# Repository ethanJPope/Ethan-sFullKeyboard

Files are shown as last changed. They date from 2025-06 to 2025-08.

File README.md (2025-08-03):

# Full Keyboard

My keybaord is a 100% version with a hotswappable pcb with custom USB_C Daughter Board PCB. 

## Why I made this Project
- I want a finished project
- Learn how to make a complex pcb
- Make a full and finished CAD Project

## PCB

**Keyboard PCB**

 

**USB_C DAUGHTER BOARD**

 

## CAD


## Final Product
0047bdcb-f9c8-4a06-a499-ea2659d34d8d~1

## BOM

| Item | Description | Unit Price | Supplier |
|---|---|---|---|
| 1 | Custom Keyboard PCB | $55.82 | JLCPCB |
| 2 | PCB Components | $22.54 | LCSC |
| 3 | USB-C Cable | $6.23 | AliExpress |
| 4 | Hot Swap Sockets | $6.90 | AliExpress |
| 5 | Stabilizers | $5.97 | AliExpress |
| 6 | Switches | $21.65 | AliExpress |
| 7 | Poron Foam | $5.70 | AliExpress |
| 8 | Keycaps Set | $19.99 | Amazon |

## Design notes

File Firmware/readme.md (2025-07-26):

# full_keyboard

full_keyboard

*A short description of the keyboard/project*

* Keyboard Maintainer: [EthanP](https://github.com/ethanJPope)
* Hardware Supported: *The PCBs, controllers supported*
* Hardware Availability: *Links to where you can find this hardware*

Make example for this keyboard (after setting up your build environment):

    make full_keyboard:default

Flashing example for this keyboard:

    make full_keyboard:default:flash

See the [build environment setup](https://docs.qmk.fm/#/getting_started_build_tools) and the [make instructions](https://docs.qmk.fm/#/getting_started_make_guide) for more information. Brand new to QMK? Start with our [Complete Newbs Guide](https://docs.qmk.fm/#/newbs).

## Bootloader

Enter the bootloader in 3 ways:

* **Bootmagic reset**: Hold down the key at (0,0) in the matrix (usually the top left key or Escape) and plug in the keyboard
* **Physical reset button**: Briefly press the button on the back of the PCB - some may have pads you must short instead
* **Keycode in layout**: Press the key mapped to `QK_BOOT` if it is available

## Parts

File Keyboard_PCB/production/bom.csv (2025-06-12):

Designator | Footprint | Quantity | Value | LCSC Part #
"-"1, "0"1, "1, "1"1, "2"1, "3"1, "4"1, "5"1, "6"1, "7"1, "8"1, "9"1, "="1, "?"1, ;1, <1, >1, A1, B1, C1, D105, Delete1, DownArrow1, E1, ESC1, End1, F10, F11, F12, F13, F2, F3, F4, F5, F6, F7, F8, F9, Func1, G1, H1, Home1, I1, Insert1, J2, K1, L1, LeftArrow1, M1, N1, Num*1, Num-1, Num.1, Num/1, Num1, Num2, Num3, Num4, Num5, Num6, Num7, Num8, Num9, NumLock1, O1, P1, PauseBreak1, PgDn1, PgUp1, PrtSc1, Q1, R4, RightArrow1, S1, ScrollLock1, T1, Tilde1, U2, UpArrow1, V1, W1, X1, Y1, Z1, {1, }1 | Hotswap_MX_1.00u | 86 | Keyswitch
Backspace1, Num0 | Hotswap_MX_2.00u | 2 | Keyswitch
C10, C11, C13, C16, C7 | Capacitor_0402 | 5 | 100nF | C307331
C12, C17 | Capacitor_0402 | 2 | 4.7uF | C23733
C14 | Capacitor_0402 | 1 | 10nF | C15195
C15 | Capacitor_0402 | 1 | 1uF | C52923
CapsLock1 | Hotswap_MX_1.75u | 1 | Keyswitch
D1, D10, D100, D101, D102, D103, D104, D11, D12, D13, D14, D15, D16, D17, D18, D19, D2, D20, D21, D22, D23, D24, D25, D26, D27, D28, D29, D3, D30, D31, D32, D33, D34, D35, D36, D37, D38, D39, D4, D40, D41, D42, D43, D44, D45, D46, D47, D48, D49, D5, D50, D51, D52, D53, D54, D55, D56, D57, D58, D59, D6, D60, D61, D62, D63, D64, D65, D66, D67, D68, D69, D7, D70, D71, D72, D73, D74, D75, D76, D77, D78, D79, D8, D80, D81, D82, D83, D84, D85, D86, D87, D88, D89, D9, D90, D91, D92, D93, D94, D95, D96, D97, D98, D99 | Diode_SOD-123 | 104 | Diode
Enter1, Shift1 | Hotswap_MX_2.25u | 2 | Keyswitch
J3 | JST_EH_B4B-EH-A_1x04_P2.50mm_Vertical | 1 | Conn_01x04_Pin
LeftAlt1, LeftControl1, LeftWin1, Menu1, RightAlt1, RightControl1, RightWin1 | Hotswap_MX_1.25u | 7 | Keyswitch
Num+1, NumEnter1 | Hotswap_MX_2.00u_90deg | 2 | Keyswitch
R1 | Resistor_0402 | 1 | 10k | C25744
RightShift1 | Hotswap_MX_2.75u | 1 | Keyswitch
SW1 | Button_TL3342 | 1 | SW_Push | C115351
Space1 | Hotswap_MX_6.25u | 1 | Keyswitch
Tab1, \1 | Hotswap_MX_1.50u | 2 | Keyswitch
U1 | Package_LQFP-48_7x7mm_P0.5 | 1 | STM32F072CBT6 | C81720

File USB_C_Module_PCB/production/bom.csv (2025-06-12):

Designator | Footprint | Quantity | Value | LCSC Part #
C8, C9 | Capacitor_0402 | 2 | 1uF | C52923
F1 | Fuse_0603 | 1 | 500mA | C210357
J1 | USB_C_HRO_TYPE-C-31-M-12 | 1 | USB_C | C165948
J2 | JST_EH_B4B-EH-A_1x04_P2.50mm_Vertical | 1 | Conn_01x04_Pin
R2, R3 | Resistor_0402 | 2 | 5.1k | C25905
U3 | Voltage_SOT-23 | 1 | XC6206 | C5446
U4 | ESD_SOT-23-6 | 1 | USBLC6-2SC6 | C2827654

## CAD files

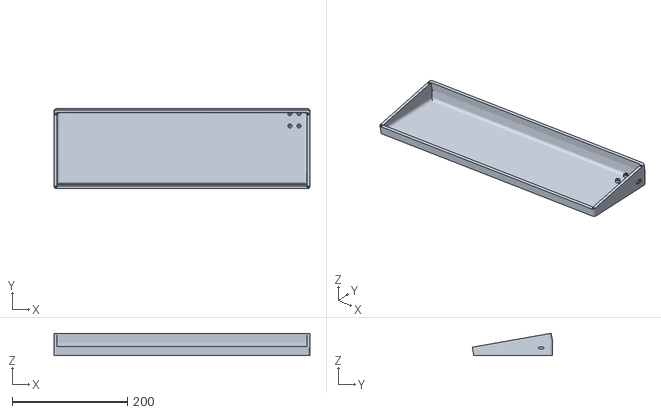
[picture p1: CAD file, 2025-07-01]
Production/BottomCase.stl
443.8 x 139.4 x 38.9

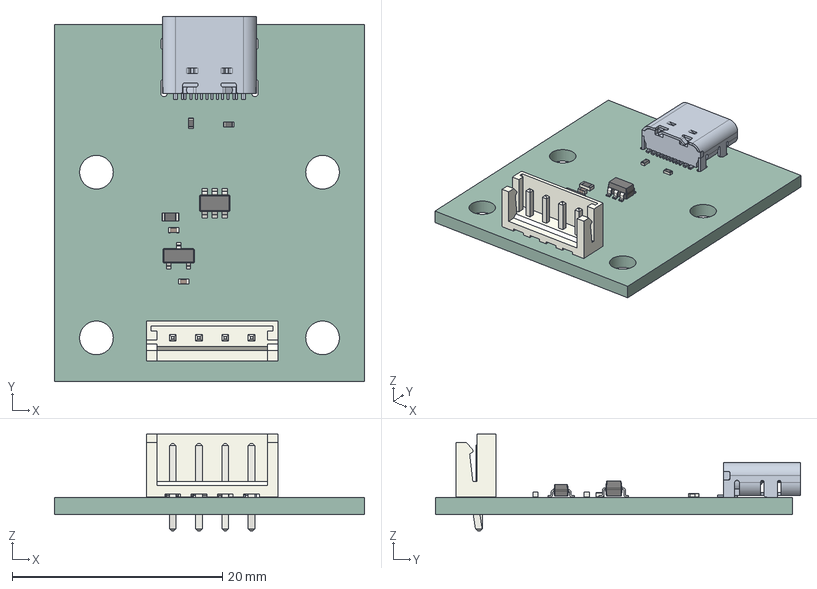
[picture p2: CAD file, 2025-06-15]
USB_C_Module_PCB/usb_c_module.step
29.5 x 34.7 x 9.20 mm
R_0402_1005Metric x 2
TYPE-C-31-M-12
SOT_23_6
C_0402_1005Metric x 2
JST_B4B_EH_A
SOT_23
Fuse_0603_1608Metric
usb_c_module_PCB

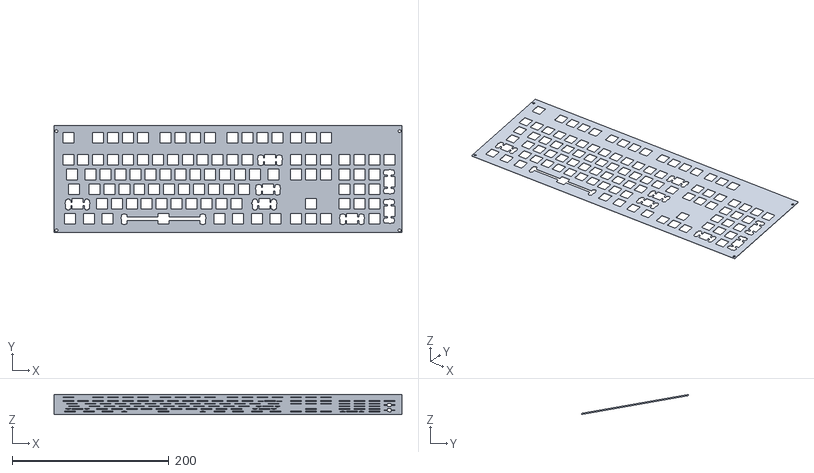
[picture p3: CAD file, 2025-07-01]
Production/Plate.stl
443.8 x 137.1 x 25.6

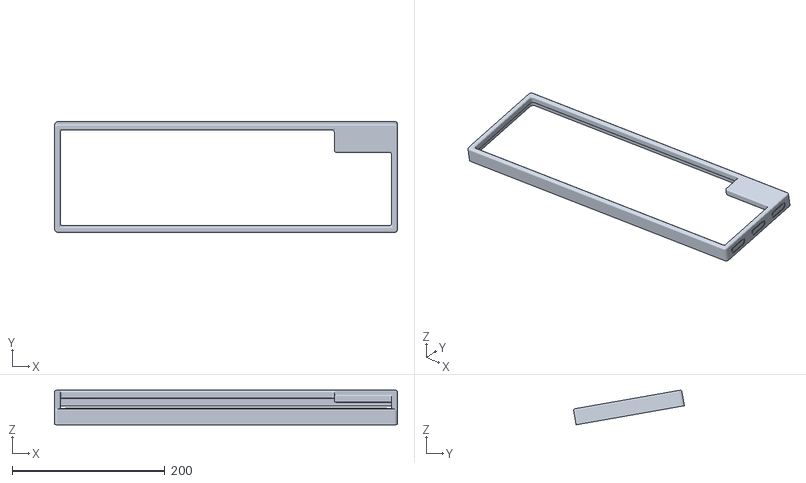
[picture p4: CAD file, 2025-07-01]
Production/TopCase.stl
448.8 x 145.1 x 45.4

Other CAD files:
USB_C_Module_PCB/Case_BTM.stl

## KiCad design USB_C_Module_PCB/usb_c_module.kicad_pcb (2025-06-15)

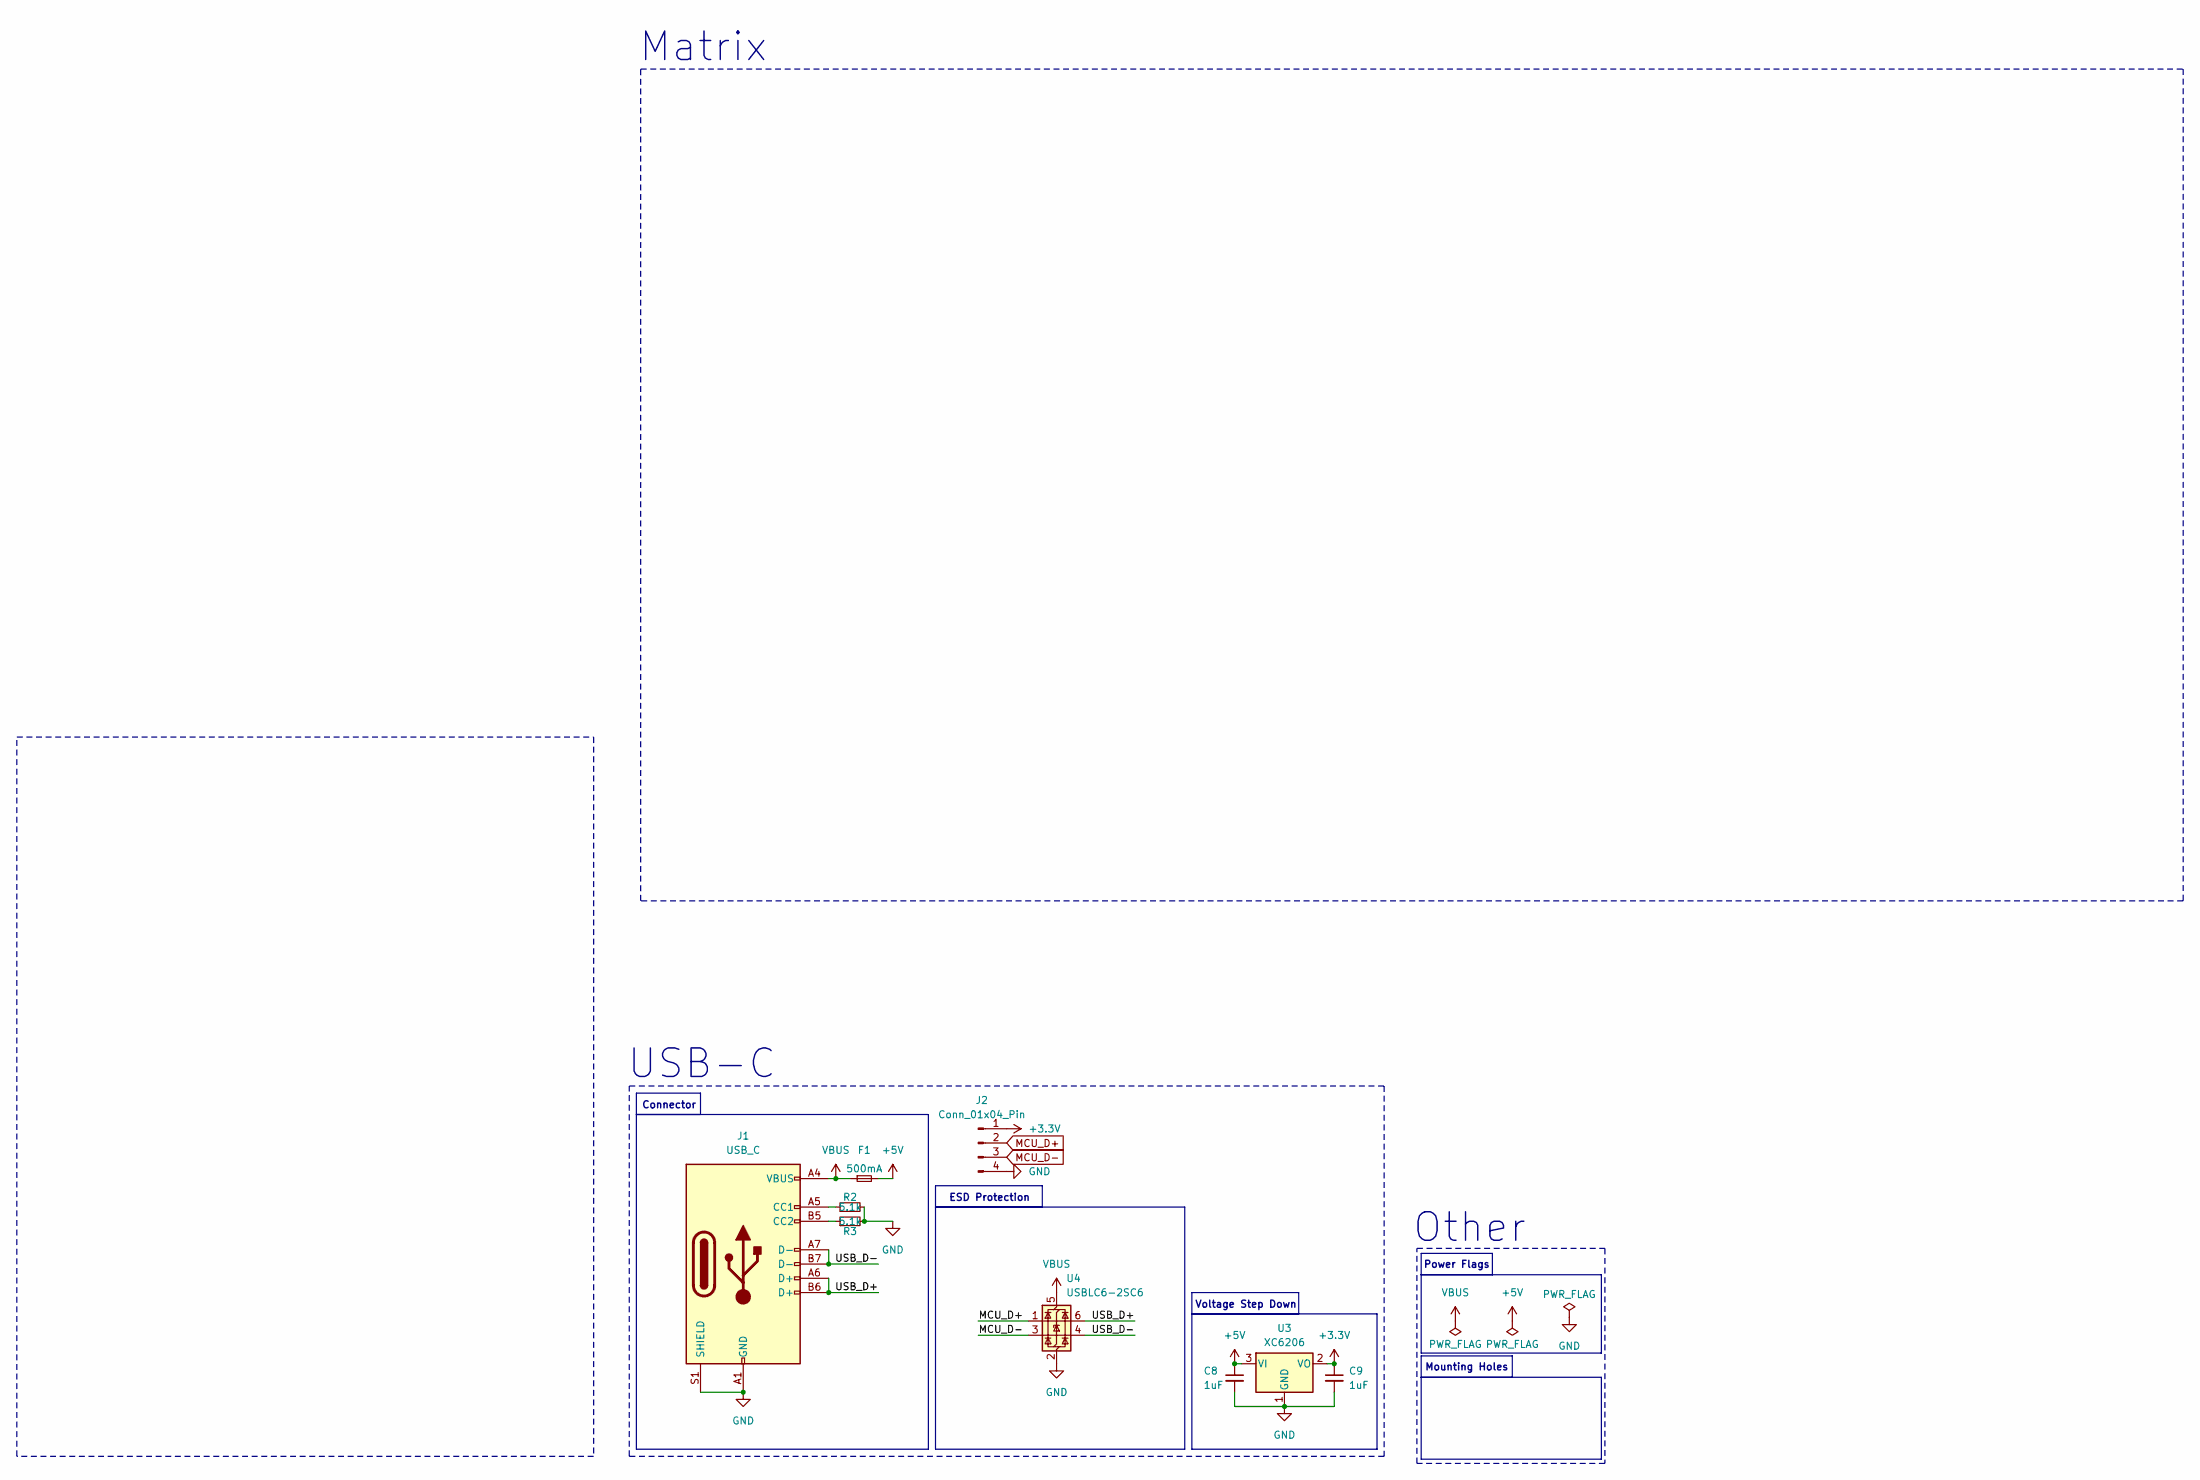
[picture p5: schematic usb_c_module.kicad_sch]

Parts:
C8, C9: 1uF; Capacitor_0402; LCSC C52923
F1: 500mA; Fuse_0603; LCSC C210357
J1: USB_C; USB_C_HRO_TYPE-C-31-M-12; LCSC C165948
J2: Conn_01x04_Pin; JST_EH_B4B-EH-A_1x04_P2.50mm_Vertical
R2, R3: 5.1k; Resistor_0402; LCSC C25905
U3: XC6206; Voltage_SOT-23; LCSC C5446
U4: USBLC6-2SC6; ESD_SOT-23-6; LCSC C2827654

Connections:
+3.3V: C9.1, J2.1, U3.2 (VO)
+5V: C8.1, F1.2, U3.3 (VI)
/USB_D+: J1.A6 (D+), J1.B6 (D+), U4.6 (I/O1)
/USB_D-: J1.A7 (D-), J1.B7 (D-), U4.4 (I/O2)
GND: C8.2, C9.2, J1.A1 (GND), J1.A12 (GND), J1.B1 (GND), J1.B12 (GND), J1.S1 (SHIELD), J2.4, R2.2, R3.2, U3.1 (GND), U4.2 (GND)
MCU_D+: J2.2, U4.1 (I/O1)
MCU_D-: J2.3, U4.3 (I/O2)
unnamed: J1.A5 (CC1), R2.1
unnamed: J1.B5 (CC2), R3.1
VBUS: F1.1, J1.A4 (VBUS), J1.A9 (VBUS), J1.B4 (VBUS), J1.B9 (VBUS), U4.5 (VBUS)

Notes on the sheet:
USB-C
Mounting Holes
ESD Protection
Power Flags
Voltage Step Down
Other
Matrix
Connector

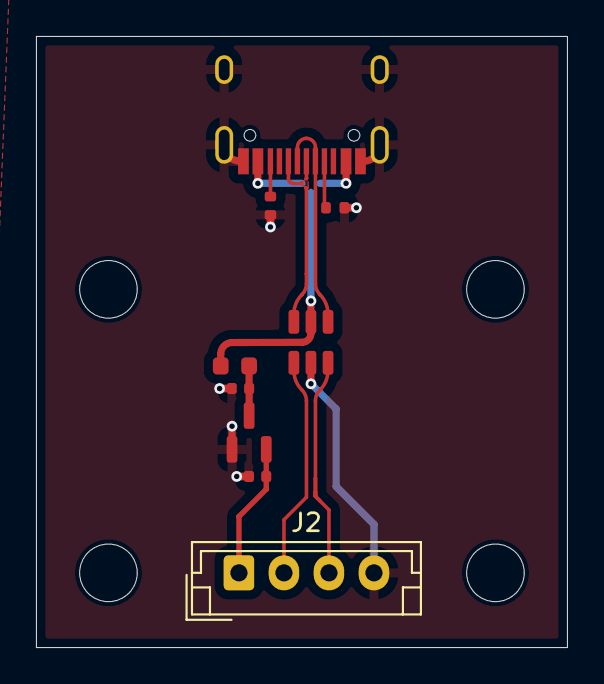
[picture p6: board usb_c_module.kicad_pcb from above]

Board: 4 copper layers, 29.5 x 34.0 mm, 9 parts (0 on the bottom side), 10 nets.

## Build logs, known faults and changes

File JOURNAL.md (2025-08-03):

---
title: "Ethan's-Full-Keyboard"
author: "Ethan Pope"
description: "I am making a full mechanical Keyboard"
created_at: "6/4/2025"
---
# Project IDEA

I want to make my very first full sized key keyboard by my self. The core reason for doing this project is to: learn more about pcb making and second is to understand the highway process works.

**Total Time spent: 43h**
# DAY 1: June 4th, 2025

## Finished the schematic and started the pcb!

**Time spent: 6h**

These hours were filled with me remembering how to use kicad. 
My big mistake when I went straight into making the schematic without planning out what I wanted. 
In the end I had to scratch it all and start again. Before I went back to kicad I went into Keyboard
Layout Editor to plan my out what I wanted the keyboard to be. This includes the layout and what rows
and columns for each key. This made it easier to make the keyboard matrix in the schematic for kicad.
I finished the schematic around 4pm. A little later I joined a hackclub call. During the call I started
my pcb design. I only got about a third of the way done with the design before I had to stop and leave
the call because I left for FRC robotics. **Shoutout Plasma Robotics!!**

# Keyboard Design and Rows/Columns

# Keyboard Schematic

# Keyboard PCB Design(Unfinished)


# DAY 2: June 5th, 2025

## FINISHING MY PCB DESIGN ##

**Time spent: 9h**

I started with placing the keys dowm to make it look a keyboard. I was having problems placing the keys in the right spot.
I later learned that there are different grids i can use, which made it a lot easier. After I had the keys laid out I then
mooved on to placing the diodes. They ended up being harder than expected to place where they would nopt intrerfeare with
anything else in the pcb. Once I finally placing the diodes, I got to work wiring. This was the longest part by far. The
main reason behind it taking so long is because I was using surface-mount hardware. This means i could only connect to 
them on one side then causing there to be a lot of vias. At last I finished the wiring, it was just touch up in the end.
One thing that was a little annoying was I forgot to add stablizers. So i had to re-route a few things, but it wasn't to
bad. In the end it was a fun process that took a while but rewarding in the end.

# PCB DESIGN

# FRONT 3D VIEW
Full Keyboard Front
# BACK 3D VIEW
Full Keyboard Back

# DAY 3: June 8th, 2025

## Started CAD for my case!!
**Time spent: 8h**

This day was all about cad. I spent basically the first hour - 2hours planning out what I wanted the keyboard to look like.
It was quite a fun process of first creating the basic sketch then slowly adding the that sketch. Sadly you can't see this
in the picture becuase I had drawn on one design instead of splitting it up. One big mistake i made was thinking it would
be simple to make this case, but by the end of the day I am only half way to the end of this case design. The steps I took
to make this case goes as follows. First, I imported my 3d pcb to use as a referance. Second, I desided on the mounting type
for the case. I was mainly deciding between a Top Mount Design or a Gasket Mount Design. In the end I chose a Gasket Mount
because I thought it could sound better even if it makes the design a little harder. Third, I went through the long and hard 
process of making the plate. What made it so hard was how I added extra padding on the sides of the pcb with a different size
on every side. So I couldn't use those automated plate makers. I ended up making my own plate, which took almost an hour by
itself. Lastly for the day was making a rough to part of the case. This didn't end up being to bad to make because of my
preemptive planning. Today was I fun test on what knowledge of Fusion 360. I learned a lot in this session about my 
patience.

# Keyboard Desgin Prototyping



# Mounting Types


# Keyboard Plate


# Top Part Of the Case(not event close to done just and outline)


# Day 4 Jun 11, 2025

## READY TO SUBMIT MY DESIGN!!

**Time Spent: 10h**

Today was probably my most productive day that I have had after starting this project. Today started out with me cading the bottom
part of the case. As I was finishing the cad for the case I relized the usb-c port was covered up, but if I were to cut a hole for
the usb it would look really bad. So I made the desision to make the usb-c port on a separate daughter board instead of directally
on the pcb. So I spent an hour designing another pcb. After I finished that I added it to my cad file. Once I did that I cut out a
hole for the port. Then I added some threads and mounting holes so the parts of the case so thaey can be put together. Lastly, I
spent an 4-5 hours improving my design and make it easier to manufacture. This means no fillets so which may make it a little bad
in the cad model, but when I put it together I can just sand down the corners.

# Final CAD Model


# USB_C Daughter Board


# Bottom Part of the Case with USBC


# Day 5 June 29, 2025

## Ready For Resubmission

**Time spent 4h**

This entire week i ahve been gone at my grandparents so I was hopiong that my keyboard would pass so I could order my parts and case,
but sadly it didn't. I had origanally planed to have my case manufactured at my local shop but they are having problems right now so,
had to resort to 3d printing it at my house. The big chellange and the reason I had been rejected is my case has sharp edges (origanally
to make it easier to machine with a cnc). To solve this I then added fillets to give some more stability to the right angles. I was then
tasked to add some of my own design, but I am not very skilled at complex designs so I made some fun oval shapes on the side of the case,
which I plan on putting some3d printing fillament in to give a pop of color. This took quite a while to get right.

# New Keyboard Design


# Day 6 Aug 1, 2025

## Starting to Put my Keyboard Together

**Time spent 6h**

Today I started with soldering all my parts. The hardest part was the tiny parts. To  make this easir I was able to borrow a microscope from
one of my robotics mentor. That was the majority of my time (about 4hr). Then I setup my prints, but after 10 min or so it I noticed filiment
was not coming out. This was because it was gunking up in the nozel, and I could not fix it. So instead I asked my freind to print them for me
(He has 2 X1 Carbons). I also went to my friends house to cut my plate the setup was the longest part, which was about 30 min. Then we could 
just let it cut for about an 1.5 hr while we were at the park. Lastly I pust all of the parts together and tested it, but when I tested it some
keys did not work. I had justy forget to solder one side of some hotswap sockets.

# Main Keyboard PCB



# USB Module PCB


# Plate CNCing
aafd38d2-0144-485e-ba0d-10ac9b6bb84e~1 (1)

# 3D Printed Case


# Final Product
0047bdcb-f9c8-4a06-a499-ea2659d34d8d~1

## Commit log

2025-06-04 First Push
    [Full Keyboard.kicad_pcb, Full Keyboard.kicad_sch]
2025-06-05 commit during highway call
    [Full Keyboard.kicad_pcb, untitled.kicad_sch]
2025-06-06 PCB Design
    [Full Keyboard.kicad_pcb, Full Keyboard.kicad_sch, untitled.kicad_sch]
2025-06-12 Update Full Keyboard.csv
    [Full Keyboard.csv]
